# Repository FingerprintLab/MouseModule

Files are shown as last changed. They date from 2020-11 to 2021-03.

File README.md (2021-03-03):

# MouseModule

This is an eurorack module that processes mouse events through the [Raspberry Pi Zero](https://www.raspberrypi.org/documentation/hardware/raspberrypi/spi/README.md) and [MCP4922](http://ww1.microchip.com/downloads/en/DeviceDoc/22250A.pdf) and outputs 2 CV signals (for the X and Y coordinates) a `GATE` signal (controlled by the left button) and a `TRIGGER` signal (controlled by the right button). It has also recording and playback capabilities with more complex mice.  

## Hardware

2 mice version


1 mouse version


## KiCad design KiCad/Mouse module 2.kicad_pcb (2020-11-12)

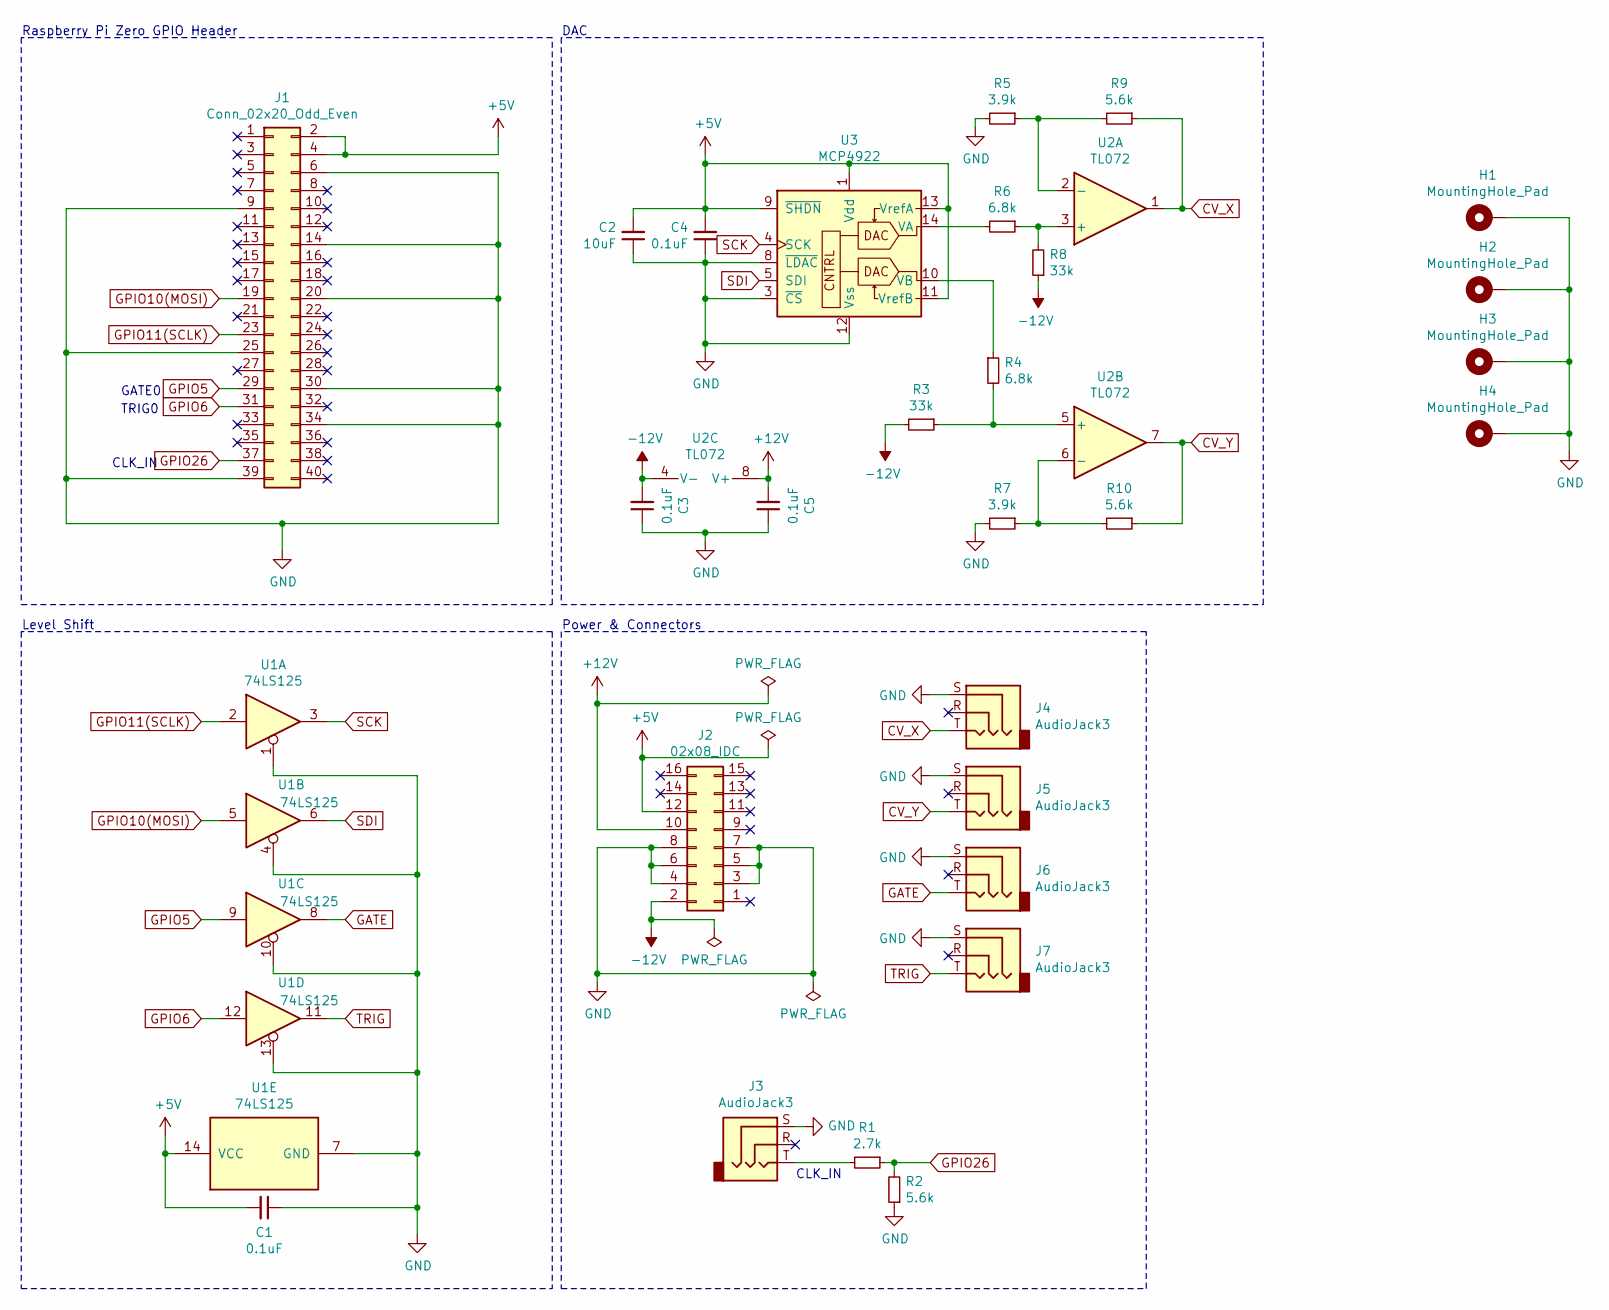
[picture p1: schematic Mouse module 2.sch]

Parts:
C1, C3, C4, C5: 0.1uF; C_Disc_D4.7mm_W2.5mm_P5.00mm
C2: 10uF; C_Disc_D4.7mm_W2.5mm_P5.00mm
H1, H2, H3, H4: MountingHole_Pad; MountingHole_2.7mm_Pad
J1: Conn_02x20_Odd_Even; PinSocket_2x20_P2.54mm_Vertical
J2: 02x08_IDC; IDC-Header_2x08_P2.54mm_Vertical
J3, J4, J5, J6, J7: AudioJack3; CUI_SJ1-3533
R1: 2.7k; R_Axial_DIN0207_L6.3mm_D2.5mm_P10.16mm_Horizontal
R2, R9, R10: 5.6k; R_Axial_DIN0207_L6.3mm_D2.5mm_P10.16mm_Horizontal
R3, R8: 33k; R_Axial_DIN0207_L6.3mm_D2.5mm_P10.16mm_Horizontal
R4, R6: 6.8k; R_Axial_DIN0207_L6.3mm_D2.5mm_P10.16mm_Horizontal
R5, R7: 3.9k; R_Axial_DIN0207_L6.3mm_D2.5mm_P10.16mm_Horizontal
U1: 74LS125; DIP-14_W7.62mm_Socket
U2: TL072; DIP-8_W7.62mm_Socket
U3: MCP4922; DIP-14_W7.62mm_Socket

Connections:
+5V: C1.2, C2.2, C4.2, J1.2, J1.4, J2.12, U1.14 (VCC), U3.1 (Vdd), U3.9 (~SHDN), U3.11 (VrefB), U3.13 (VrefA)
+12V: C5.2, J2.10, U2.8 (V+)
-12V: C3.2, J2.2, R3.2, R8.1, U2.4 (V-)
CV_X: J4.T, R9.1, U2.1
CV_Y: J5.T, R10.1, U2.7
GATE: J6.T, U1.8
GND: C1.1, C2.1, C3.1, C4.1, C5.1, H1.1, H2.1, H3.1, H4.1, J1.6, J1.9, J1.14, J1.20, J1.25, J1.30, J1.34, J1.39, J2.3, J2.4, J2.5, J2.6, J2.7, J2.8, J3.S, J4.S, J5.S, J6.S, J7.S, R2.1, R5.2, R7.2, U1.1, U1.4, U1.7 (GND), U1.10, U1.13, U3.3 (~CS), U3.8 (~LDAC), U3.12 (Vss)
GPIO5: J1.29, U1.9
GPIO6: J1.31, U1.12
GPIO10(MOSI): J1.19, U1.5
GPIO11(SCLK): J1.23, U1.2
GPIO26: J1.37, R1.1, R2.2
unnamed: J3.T, R1.2
unnamed: R3.1, R4.2, U2.5 (+)
unnamed: R4.1, U3.10 (VB)
unnamed: R5.1, R9.2, U2.2 (-)
unnamed: R6.1, R8.2, U2.3 (+)
unnamed: R6.2, U3.14 (VA)
unnamed: R7.1, R10.2, U2.6 (-)
SCK: U1.3, U3.4 (SCK)
SDI: U1.6, U3.5 (SDI)
TRIG: J7.T, U1.11

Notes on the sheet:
Level Shift
Power & Connectors
DAC
Raspberry Pi Zero GPIO Header
CLK_IN
GATE0
TRIG0

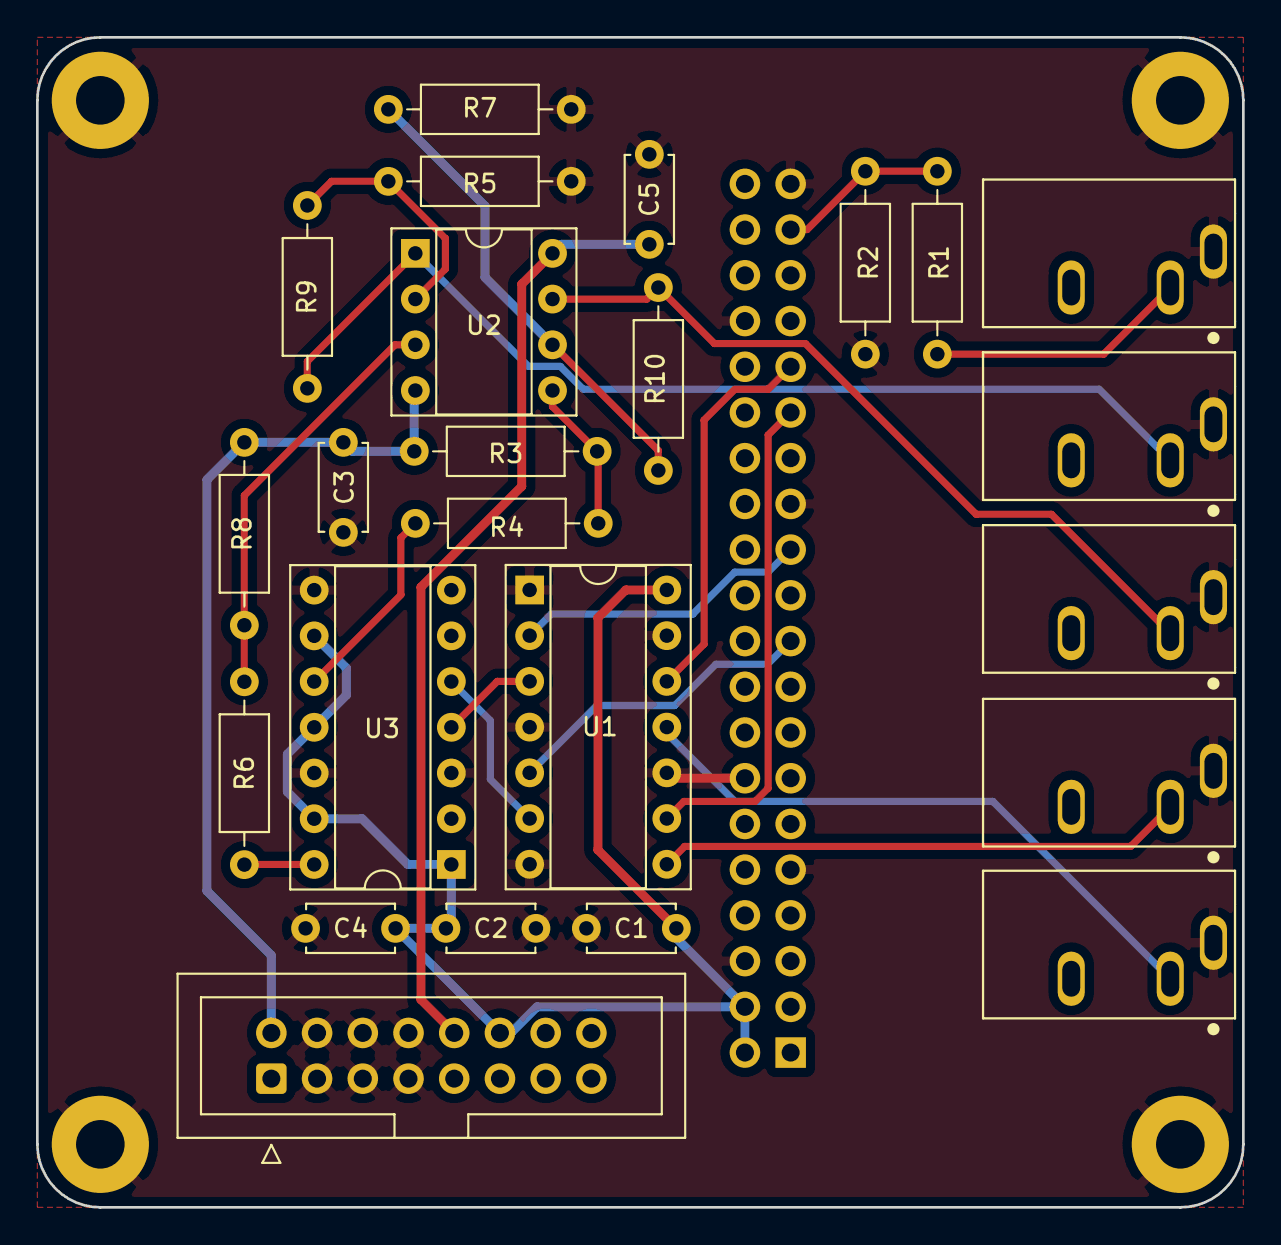
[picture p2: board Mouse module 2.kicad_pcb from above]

Board: 2 copper layers, 67.0 x 65.0 mm, 29 parts (1 on the bottom side), 22 nets.

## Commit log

2020-11-03 New schematic
    [Mouse module.kicad_pcb, Mouse module.sch]
2020-11-03 Included new schematic
2020-11-12 initial commit of one mouse version
    [Mouse module 2-B_Cu.gbr, Mouse module 2-B_Mask.gbr, Mouse module 2-B_SilkS.gbr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]
2020-12-08 Resolved wheel event issue
2021-01-06 current library update
2021-01-16 mouse buttons recognized
2021-01-19 first WSL commit
    [Mouse module 2-B_Cu.gbr, Mouse module 2-B_Mask.gbr, Mouse module 2-B_SilkS.gbr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]
2021-02-26 cleaned repository
    [Mouse module 2-B_Cu.gbr, Mouse module 2-B_Mask.gbr, Mouse module 2-B_SilkS.gbr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]
